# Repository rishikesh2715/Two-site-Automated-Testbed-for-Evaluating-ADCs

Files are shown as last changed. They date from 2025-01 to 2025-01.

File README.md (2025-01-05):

# Two-site-Automated-Testbed-for-Evaluating-ADCs

## Overview
The Two-site Automated Test System (ATS-2) is a custom-designed testbed for evaluating ADCs, specifically focused on testing the ADS7816. This comprehensive testing solution consists of a custom-designed device interface board, National Instruments VirtualBench integration, and automated test programs implemented in Python.

### Key Features:
- **Dual Testing Sites**: Capability to test two ADC devices simultaneously
- **Comprehensive Test Suite**: Includes all relevant parametric and functional tests
- **Automated Control**: Python-based test automation for consistent results
- **Relay-Based Interface**: Flexible configuration using G5NB-1A4 DC24 and J104D2C24VDC.15S relays
- **Power Management**: External 24V power supply for relay control

## Test Capabilities
The ATS-2 supports a comprehensive suite of tests including:
- Continuity Testing
- Power Supply Current Testing (Normal and Power-down modes)
- Leakage Current Testing
- Input Impedance Testing
- Linear Histogram Method for Code Edge Measurements
- Sinusoidal Histogram Method for Code Edge Measurements
- Offset and Offset Error Analysis
- Gain and Gain Error Analysis
- Missing Code Detection
- Integral Nonlinearity (INL) Analysis
- Differential Nonlinearity (DNL) Analysis
- Maximum Sampling Frequency Verification

## Hardware Specifications
### Device Under Test (DUT)
- **Target Device**: ADS7816
- **Features**: 
  - 200kHz sampling rate
  - Low power operation
  - Differential input
  - Serial interface
  - External reference and clock requirements
  - 5V power source operation

### Relay System
- **SPST-NO Relay**: G5NB-1A4 DC24
  - Power consumption: ~200mW
  - Operating current: ~8.3mA at 24V
  - Cost: $1.32

- **DPDT Relay**: J104D2C24VDC.15S
  - Power consumption: 150mW
  - Operating current: ~6.25mA at 24V
  - Cost: $1.21

## Software
The testbed includes a comprehensive suite of Python scripts for automated testing:
- `Combined_Hist_Tests.py`: Manages both linear and sinusoidal histogram testing
- `Continuity.py`: Performs continuity testing across all pins
- `InputImpedanceTest.py`: Measures input impedance characteristics
- `LeakageCurrents.py`: Tests for current leakage under various conditions
- `PwrSupplyCurrents.py`: Evaluates power supply current in different operating modes
- `Testing_Comb.py`: Main test orchestration script

## Getting Started
1. **Hardware Setup**:
   - Connect the VirtualBench device (VB8012-30DF182)
   - Apply 24V external power for relay control
   - Connect the DUT to the test board

2. **Software Requirements**:
   - Python 3.x
   - PyVirtualBench library
   - Required Python packages: numpy, matplotlib, tqdm, pandas

3. **Running Tests**:
   ```bash
   python Testing_Comb.py

## PCBWay - PCB Manufacturing and Assembly
![PCBWay](./Images/pcbway.png)
This project was proudly sponsored by **PCBWay**, a leading PCB manufacturer and assembler. They provided high-quality PCB manufacturing and assembly services, ensuring that the ATS-2 board was produced to the highest standards. Here's why PCBWay is a great choice for PCB production:

- **Exceptional Quality**: The PCBs produced by PCBWay have excellent build quality, with precise soldering and thorough assembly.
- **Fast Service**: PCBWay offers quick turnaround times, so your project can stay on track.
- **Comprehensive Services**: From prototyping to mass production, PCBWay provides services for all stages of PCB development, including multi-layer PCBs, advanced PCBs, flexible PCBs, and assembly services.
- **Affordable Pricing**: PCBWay offers competitive pricing without compromising quality.

To order this board through PCBWay:
1. Upload the provided Gerber files to PCBWay's portal
2. Select your preferences:
   - Min Track/spacing: 6/6 mil
   - Min hole size: 0.2mm
   - Recommended finish: Immersion Gold (ENIG)

If you're looking for a reliable partner to bring your PCB projects to life, check out [PCBWay](https://pcbway.com). With their extensive capabilities and top-notch customer support, PCBWay is the ideal choice for makers, engineers, and businesses alike.

## PCB Features
- Custom designed device interface board
- Relay-based switching matrix for flexible test configuration
- Support for dual device testing
- Professional 4-layer PCB design
- Integrated power management for both DUT and relay control
- Comprehensive test point access
- Industrial-grade components for reliability

## License
This project is open-source and available under the MIT License.

## Contributing
Contributions are welcome! Please feel free to submit pull requests or open issues for improvements and bug fixes.

## Acknowledgments
- Mr. Johnston and Dr. Dallas at Texas Tech University for project supervision
- National Instruments for VirtualBench support
- PCBWay for manufacturing partnership

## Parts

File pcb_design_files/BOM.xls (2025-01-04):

PCBWay Bom Quotation, Product No.:T-I6W845719A
Item # | *Designator | *Qty | Manufacturer | *Mfg Part # | Description / Value | Vendor Part # | *Package/Footprint | Mounting Type | Your Instructions / Notes | Assembly requirement | *Unit Price(1 set) | *Total | *Delivery Time | *Actual Purchase Mfg Part # | *PCBWay Note | Customer Reply | PCBWay Update
1 | C1, C4 | 2 |  |  | 5u『 』Unpolarized capacitor |  | C_Axial_L3.8mm_D2.6mm_P7.50mm_Horizontal | tht |  |  |  |  |  |  | [DNP
2 | C2, C3 | 2 |  |  | .1u『 』Unpolarized capacitor |  | C_Axial_L3.8mm_D2.6mm_P7.50mm_Horizontal | tht |  |  |  |  |  |  | [DNP
3 | IC1, IC2, IC3, IC4, IC5, IC6, IC7 | 7 | Nexperia | 74LVC595AD,118 | 74LVC595AD,118『 』74LVC595AD_118『 』IC 8BIT SHIFT REGISTER 16-SOIC『 』IC 8BIT SHIFT REGISTER 16-SOIC『 』Digikey『 』Shift Shift Register 1 Element 8 Bit 16-SO『 』74LVC595AD,118 | 1727-6688-1-ND | 74LVC595AD118『 』SO-16 Nexperia USA Inc.『 』16SOP | smt | https://www.snapeda.com/parts/74LVC595AD,118/Nexperia/view-part/?ref=eda『 』https://www.snapeda.com/parts/74LVC595AD,118/Nexperia/view-part/?ref=snap |  | $0.644 | $4.508 | 7-10 Workdays
4 | J1 | 1 | 3M Electronic Solutions Division『 』3M | 208-7391-55-1902 | DNP『 』Socket,Test&Burn-InSOIC,8Leads,0.15Width,1A,1000Vrms | 3M 208-7391-55-1902『 』38.51mm『 』Manufacturer Recommendations『 』February 19, 2001 |  | 3M_208-7391-55-1902『 』None | tht | https://www.snapeda.com/parts/208-7391-55-1902/Hartmann+Electronic/view-part/?ref=eda『 』https://www.snapeda.com/parts/208-7391-55-1902/Hartmann+Electronic/view-part/?ref=snap『 』https://www.snapeda.com/api/url_track_click_mouser/?unipart_id=12122657&manufacturer=3M Electronic Solutions Division&part_name=208-7391-55-1902&search_term=208-7391-55-1902 | DNP |  |  |  |  | [DNP
5 | J2, J8 | 2 |  |  | 25V_PS『 』Generic screw terminal, single row, 01x02, script generated (kicad-library-utils/schlib/autogen/connector/) |  | TerminalBlock_bornier-2_P5.08mm | tht |  |  | $0.505 | $1.010 |  | DB127V-5.08-2P-GN-S
6 | J3 | 1 |  |  | Multimeter『 』Generic screw terminal, single row, 01x03, script generated (kicad-library-utils/schlib/autogen/connector/) |  | TerminalBlock_bornier-3_P5.08mm | tht |  |  | $1.464 | $1.464 |  | DB127V-5.08-3P-GN-S
7 | J4 | 1 |  |  | 6V_PS『 』Generic screw terminal, single row, 01x02, script generated (kicad-library-utils/schlib/autogen/connector/) |  | TerminalBlock_bornier-2_P5.08mm | tht |  |  | $1.010 | $1.010 |  | DB127V-5.08-2P-GN-S
8 | J5 | 1 |  |  | Digital I/O『 』Generic screw terminal, single row, 01x14, script generated (kicad-library-utils/schlib/autogen/connector/) |  | PinHeader_1x14_P2.54mm_Vertical | tht |  |  | $1.226 | $1.226 |  | X6511WV-14H-C60D30
9 | J6 | 1 |  |  | FunctionGenerator『 』Generic screw terminal, single row, 01x02, script generated (kicad-library-utils/schlib/autogen/connector/) |  | TerminalBlock_bornier-2_P5.08mm | tht |  |  | $1.010 | $1.010 |  | DB127V-5.08-2P-GN-S
10 | J7 | 1 |  |  | 24V『 』Generic screw terminal, single row, 01x02, script generated (kicad-library-utils/schlib/autogen/connector/) |  | TerminalBlock_bornier-2_P5.08mm | tht |  |  | $1.010 | $1.010 |  | DB127V-5.08-2P-GN-S
11 | J9 | 1 | 3M Electronic Solutions Division『 』3M | 208-7391-55-1902 | DNP『 』Socket,Test&Burn-InSOIC,8Leads,0.15Width,1A,1000Vrms | 3M 208-7391-55-1902『 』38.51mm『 』Manufacturer Recommendations『 』February 19, 2001 |  | 3M_208-7391-55-1902『 』None | tht | https://www.snapeda.com/parts/208-7391-55-1902/Hartmann+Electronic/view-part/?ref=eda『 』https://www.snapeda.com/parts/208-7391-55-1902/Hartmann+Electronic/view-part/?ref=snap『 』https://www.snapeda.com/api/url_track_click_mouser/?unipart_id=12122657&manufacturer=3M Electronic Solutions Division&part_name=208-7391-55-1902&search_term=208-7391-55-1902 | DNP |  |  |  |  | [DNP
12 | K1, K10, K11, K12, K13, K17, K18, K20, K21, K23, K24, K25, K26, K27, K28, K29, K3, K32, K33, K34, K36, K37, K38, K39, K4, K40, K41, K42, K43, K44, K45, K46, K47, K48, K49, K5, K50, K51, K52, K53, K54, K55, K56, K59, K6, K7, K8, K9 | 48 | Omron Electronics | OJ-SS-112LMH2 | OJ-SS-112LMH2『 』Body Features: Insulation Special Features Tracking Index of Relay Base PTI250 | Product Weight 9 G | Product Weight .318 OZ | Contact Features: Contact Current Rating (Max) 8 AMP | Contact Arrangement 1 Form A (NO) | Contact Current Class 16 AMP | Contact Number of Poles 1 | Contact Material AgSnOInO | Dimensions: Product Width .401 INCH | Product Length 18.2 MM | Insulation Clearance Between Contact & Coil .125 INCH | Product Length .716 INCH | Product Height 14.7 MM | Length Class (Mechanical) 16 20『 』15.4 | 655-OJ-SS-112LMH2 | G5NB1A4DC5 | tht | https://www.mouser.co.uk/ProductDetail/TE-Connectivity-OEG/OJ-SS-112LMH2?qs=rXmh1mW8ce0s4UUbiGzobQ%3D%3D |  | $1.983 | $95.184 | 7-10 Workdays | G5NB-1A4 DC24
13 | K14, K15, K16, K22, K30, K31 | 6 | CIT Relay and Switch | G6K-2P-Y DC9 | G6K-2P-Y_DC9『 』Low Signal Relays - PCB ThruHole NoLatch 3.2 DPDT 9VDC 100mW | 653-G6K-2P-YDC9 | J104D2C24VDC.15S | tht | https://www.mouser.co.uk/ProductDetail/Omron-Electronics/G6K-2P-Y-DC9?qs=wkx8pu8tL7LXpnqEum69xQ%3D%3D |  | $2.282 | $13.692 | 7-10 Workdays | J104D2C24VDC.15S
14 | Q1, Q10, Q11, Q12, Q13, Q14, Q15, Q16, Q18, Q19, Q2, Q20, Q21, Q22, Q23, Q24, Q25, Q26, Q27, Q28, Q3, Q30, Q33, Q34, Q35, Q37, Q38, Q39, Q4, Q40, Q41, Q42, Q43, Q44, Q45, Q46, Q47, Q48, Q5, Q50, Q51, Q52, Q53, Q54, Q55, Q56, Q57, Q58, Q6, Q61, Q7, Q8, Q9, Qa21 | 54 | Vishay | IRL540PBF | IRL540PBF『 』MOSFET N-CH 100V HEXFET MOSFET『 』4.65 | 844-IRL540PBF | TO254P465X1024X2050-3P | tht | https://www.mouser.co.uk/ProductDetail/Vishay-Semiconductors/IRL540PBF?qs=cvaI6ThkwxvX4jX2UNqT3g%3D%3D |  | $1.769 | $95.526 | 7-10 Workdays
15 | R1, R10, R101, R103, R105, R107, R112, R115, R12, R14, R17, R19, R20, R21, R22, R23, R24, R26, R27, R29, R31, R32, R35, R37, R38, R4, R40, R42, R43, R45, R47, R49, R5, R51, R52, R54, R55, R56, R57, R58, R61, R63, R66, R69, R7, R71, R73, R75, R80, R83, R86, R9, R97, R99 | 54 |  |  | 2k『 』Resistor, US symbol |  | R_0805_2012Metric_Pad1.20x1.40mm_HandSolder | smt |  |  | $0.002 | $0.108 |  | RC0805FR-072KL
16 | R100, R102, R104, R106, R108, R11, R111, R113, R114, R116, R117, R118, R119, R124, R13, R15, R16, R18, R2, R25, R28, R3, R34, R36, R39, R41, R44, R46, R48, R50, R53, R59, R6, R60, R64, R65, R67, R68, R70, R72, R74, R76, R79, R8, R81, R82, R84, R85, R87, R92, R93, R94, R98, Ra79 | 54 |  |  | 10k『 』Resistor, US symbol |  | R_0805_2012Metric_Pad1.20x1.40mm_HandSolder | smt |  |  | $0.004 | $0.216 |  | RC0805FR-0710KL
17 | R30, R33 | 2 |  |  | 1R『 』Resistor, US symbol |  | R_0805_2012Metric_Pad1.20x1.40mm_HandSolder | smt |  |  | $0.107 | $0.214 |  | RC0805FR-071RL
 |  |  |  |  |  |  |  |  |  |  | Component Cost | $216.18
 |  |  |  |  |  |  |  |  |  |  | Assembly Cost | $88.00
 |  |  |  |  |  |  |  |  |  |  | PCB Cost | $133.63
 |  |  |  |  |  |  |  |  |  |  | V1 Member 1% off | -$2.22
 |  |  |  |  |  |  |  |  |  |  | All Total 1 Sets | $435.59
客户BOM中部分没有型号，推荐了*Actual Purchase Mfg Part # *PCBWay Note请确认

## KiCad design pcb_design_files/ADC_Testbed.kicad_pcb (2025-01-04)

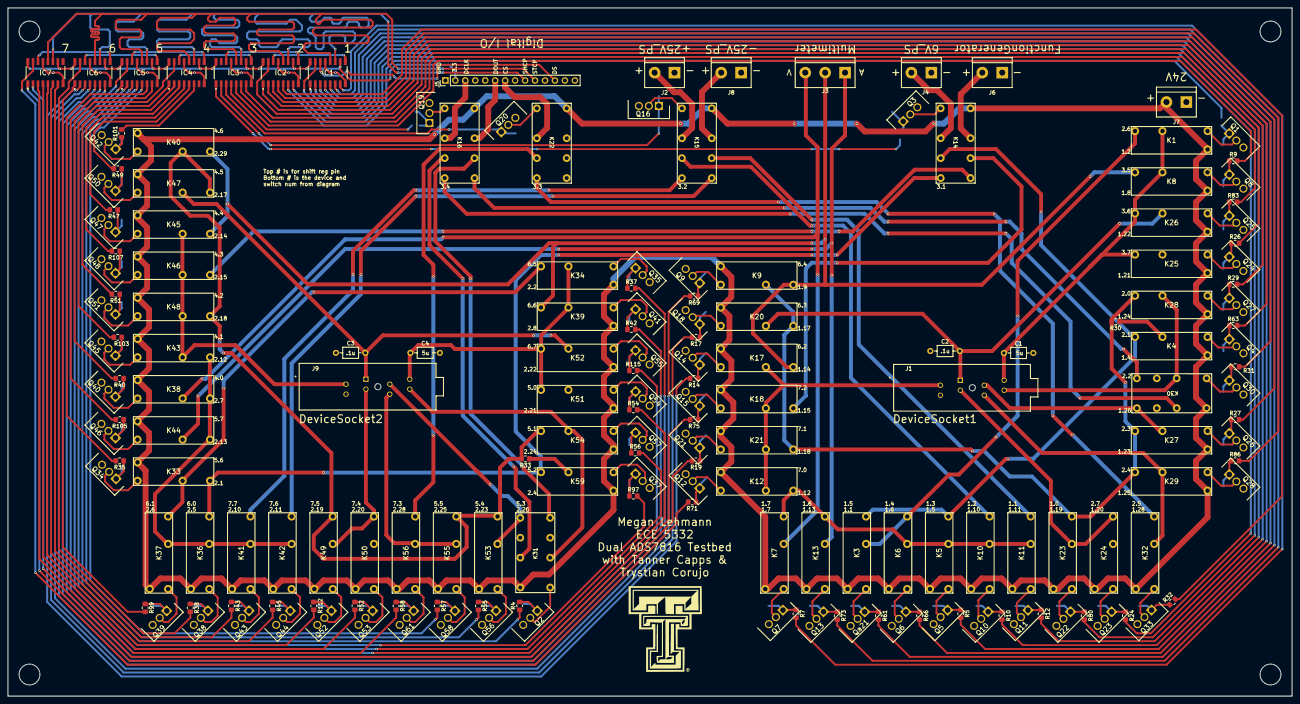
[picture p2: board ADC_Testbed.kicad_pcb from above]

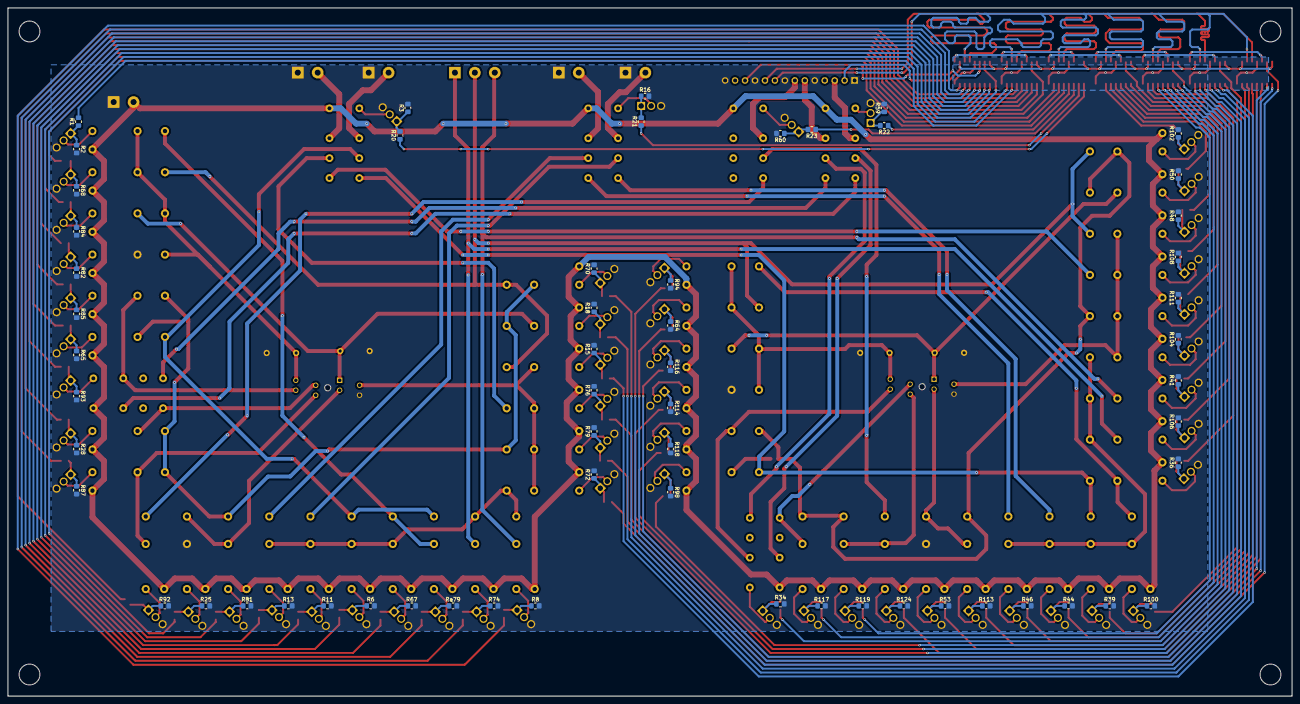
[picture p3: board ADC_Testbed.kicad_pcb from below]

Board: 2 copper layers, 327.5 x 175.5 mm, 238 parts (59 on the bottom side), 220 nets.

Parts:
C1, C4: 5u; C_Axial_L3.8mm_D2.6mm_P7.50mm_Horizontal
C2, C3: .1u; C_Axial_L3.8mm_D2.6mm_P7.50mm_Horizontal
IC1, IC2, IC3, IC4, IC5, IC6, IC7: 74LVC595AD_118; 74LVC595AD118
J1, J9: DNP; 3M_208-7391-55-1902
J2: +25V_PS; TerminalBlock_bornier-2_P5.08mm
J3: Multimeter; TerminalBlock_bornier-3_P5.08mm
J4: 6V_PS; TerminalBlock_bornier-2_P5.08mm
J5: Digital I/O; PinHeader_1x14_P2.54mm_Vertical
J6: FunctionGenerator; TerminalBlock_bornier-2_P5.08mm
J7: 24V; TerminalBlock_bornier-2_P5.08mm
J8: -25V_PS; TerminalBlock_bornier-2_P5.08mm
K1, K3, K4, K5, K6, K7, K8, K9, K10, K11, K12, K13, K17, K18, K20, K21, K23, K24, K25, K26, K27, K28, K29, K32, K33, K34, K36, K37, K38, K39, K40, K41, K42, K43, K44, K45, K46, K47, K48, K49, K50, K51, K52, K53, K54, K55, K56, K59: OJ-SS-112LMH2; G5NB1A4DC5
K14, K15, K16, K22, K30, K31: G6K-2P-Y_DC9; J104D2C24VDC.15S
Q1, Q2, Q3, Q4, Q5, Q6, Q7, Q8, Q9, Q10, Q11, Q12, Q13, Q14, Q15, Q16, Q18, Q19, Q20, Q21, Q22, Q23, Q24, Q25, Q26, Q27, Q28, Q30, Q33, Q34, Q35, Q37, Q38, Q39, Q40, Q41, Q42, Q43, Q44, Q45, Q46, Q47, Q48, Q50, Q51, Q52, Q53, Q54, Q55, Q56, Q57, Q58, Q61: IRL540PBF; TO254P465X1024X2050-3P
Qa21: IRL540PBF; TO254P465X1024X2050-3P
R1, R4, R5, R7, R9, R10, R12, R14, R17, R19, R20, R21, R22, R23, R24, R26, R27, R29, R31, R32, R35, R37, R38, R40, R42, R43, R45, R47, R49, R51, R52, R54, R55, R56, R57, R58, R61, R63, R66, R69, R71, R73, R75, R80, R83, R86, R97, R99, R101, R103, R105, R107, R112, R115: 2k; R_0805_2012Metric_Pad1.20x1.40mm_HandSolder
R2, R3, R6, R8, R11, R13, R15, R16, R18, R25, R28, R34, R36, R39, R41, R44, R46, R48, R50, R53, R59, R60, R64, R65, R67, R68, R70, R72, R74, R76, R79, R81, R82, R84, R85, R87, R92, R93, R94, R98, R100, R102, R104, R106, R108, R111, R113, R114, R116, R117, R118, R119, R124: 10k; R_0805_2012Metric_Pad1.20x1.40mm_HandSolder
R30, R33: 1R; R_0805_2012Metric_Pad1.20x1.40mm_HandSolder
Ra79: 10k; R_0805_2012Metric_Pad1.20x1.40mm_HandSolder

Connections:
0: J5.3, K16.6 (COM_2)
2: J5.6, K16.3 (COM_1)
3: J5.7, K22.6 (COM_2)
4: IC1.11 (SHCP), IC2.11 (SHCP), IC3.11 (SHCP), IC4.11 (SHCP), IC5.11 (SHCP), IC6.11 (SHCP), IC7.11 (SHCP), J5.9
5: IC1.12 (STCP), IC2.12 (STCP), IC3.12 (STCP), IC4.12 (STCP), IC5.12 (STCP), IC6.12 (STCP), IC7.12 (STCP), J5.10
6: IC1.14 (DS), J5.12
+3.3V: IC1.10 (~MR), IC1.16 (VCC), IC2.10 (~MR), IC2.16 (VCC), IC3.10 (~MR), IC3.16 (VCC), IC4.10 (~MR), IC4.16 (VCC), IC5.10 (~MR), IC5.16 (VCC), IC6.10 (~MR), IC6.16 (VCC), IC7.10 (~MR), IC7.16 (VCC), J5.2
+24V: J7.2, K1.2 (COIL_2), K3.2 (COIL_2), K4.2 (COIL_2), K5.2 (COIL_2), K6.2 (COIL_2), K7.2 (COIL_2), K8.2 (COIL_2), K9.2 (COIL_2), K10.2 (COIL_2), K11.2 (COIL_2), K12.2 (COIL_2), K13.2 (COIL_2), K14.1 (COIL_+), K15.1 (COIL_+), K16.1 (COIL_+), K17.2 (COIL_2), K18.2 (COIL_2), K20.2 (COIL_2), K21.2 (COIL_2), K22.1 (COIL_+), K23.2 (COIL_2), K24.2 (COIL_2), K25.2 (COIL_2), K26.2 (COIL_2), K27.2 (COIL_2), K28.2 (COIL_2), K29.2 (COIL_2), K30.1 (COIL_+), K31.1 (COIL_+), K32.2 (COIL_2), K33.2 (COIL_2), K34.2 (COIL_2), K36.2 (COIL_2), K37.2 (COIL_2), K38.2 (COIL_2), K39.2 (COIL_2), K40.2 (COIL_2), K41.2 (COIL_2), K42.2 (COIL_2), K43.2 (COIL_2), K44.2 (COIL_2), K45.2 (COIL_2), K46.2 (COIL_2), K47.2 (COIL_2), K48.2 (COIL_2), K49.2 (COIL_2), K50.2 (COIL_2), K51.2 (COIL_2), K52.2 (COIL_2), K53.2 (COIL_2), K54.2 (COIL_2), K55.2 (COIL_2), K56.2 (COIL_2), K59.2 (COIL_2)
+HighVoltage: J2.2, K15.6 (COM_2)
-HighVoltage: J8.2, K15.3 (COM_1)
/Relay_Control1/OUT: K1.3 (COM), K3.4 (NO), K6.3 (COM)
/Relay_Control2/OUT: C1.1, J1.8, K1.4 (NO), K8.4 (NO), K25.3 (COM), K26.3 (COM)
/Relay_Control4/OUT: K4.4 (NO), R30.1
/Relay_Control10/OUT: K5.4 (NO), K6.4 (NO), K7.3 (COM), K10.4 (NO), K11.4 (NO), K12.3 (COM), K13.3 (COM)
/Relay_Control12/OUT: J1.2, K12.4 (NO), K17.4 (NO), K18.4 (NO), K21.4 (NO)
/Relay_Control17/IN: K9.4 (NO), K20.3 (COM), K21.3 (COM), K23.3 (COM), K27.3 (COM), K28.3 (COM), K29.3 (COM), R30.2
/Relay_Control17/OUT: C2.2, J1.1, K20.4 (NO), K26.4 (NO)
/Relay_Control19/OUT: J1.3, K23.4 (NO), K24.3 (COM)
/Relay_Control23/OUT: J1.7, K27.4 (NO), K30.4 (N.O._1)
/Relay_Control24/OUT: J1.6, K28.4 (NO), K30.6 (COM_2)
/Relay_Control25/OUT: J1.5, K29.4 (NO), K32.4 (NO)
/Relay_Control29/OUT: K33.4 (NO), K34.3 (COM), K37.3 (COM)
/Relay_Control30/OUT: C4.1, J9.8, K34.4 (NO), K39.4 (NO), K51.3 (COM), K52.3 (COM)
/Relay_Control32/OUT: K59.4 (NO), R33.1
/Relay_Control33/OUT: K36.4 (NO), K37.4 (NO), K38.3 (COM), K41.4 (NO), K42.4 (NO), K43.3 (COM), K44.3 (COM)
/Relay_Control37/OUT: K40.4 (NO), K47.3 (COM), K48.3 (COM), K49.3 (COM), K53.3 (COM), K54.3 (COM), K55.3 (COM), R33.2
/Relay_Control40/OUT: J9.2, K43.4 (NO), K45.4 (NO), K46.4 (NO), K48.4 (NO)
/Relay_Control45/OUT: C3.2, J9.1, K47.4 (NO), K52.4 (NO)
/Relay_Control47/OUT: J9.3, K49.4 (NO), K50.3 (COM)
/Relay_Control51/OUT: J9.7, K31.4 (N.O._1), K53.4 (NO)
/Relay_Control52/OUT: J9.6, K31.6 (COM_2), K54.4 (NO)
/Relay_Control53/OUT: J9.5, K55.4 (NO), K56.4 (NO)
Ammeter: J3.1, K13.4 (NO), K44.4 (NO)
CS_1: IC3.1 (Q1), R20.1
CS_2: IC3.2 (Q2), R21.1
CS_3: IC3.4 (Q4), R22.1
CS_4: IC3.3 (Q3), R23.1
D1CS1: IC1.5 (Q5), R61.2
D1CS2: IC2.6 (Q6), R1.2
D1CS4: IC2.1 (Q1), R63.2
D1CS5: IC1.3 (Q3), R5.2
D1CS6: IC1.4 (Q4), R66.2
D1CS7: IC1.7 (Q7), R7.2
D1CS8: IC3.5 (Q5), R9.2
D1CS9: IC6.4 (Q4), R69.2
D1CS10: IC1.2 (Q2), R10.2
D1CS11: IC1.1 (Q1), R12.2
D1CS12: IC7.15 (Q0), R71.2
D1CS13: IC1.6 (Q6), R73.2
D1CS14: IC6.2 (Q2), R14.2
D1CS15: IC7.2 (Q2), R75.2
D1CS17: IC6.3 (Q3), R17.2
D1CS18: IC7.1 (Q1), R19.2
D1CS19: IC1.15 (Q0), R80.2
D1CS20: IC2.7 (Q7), R24.2
D1CS21: IC3.7 (Q7), R26.2
D1CS22: IC3.6 (Q6), R83.2
D1CS23: IC2.3 (Q3), R27.2
D1CS24: IC2.15 (Q0), R29.2
D1CS25: IC2.4 (Q4), R86.2
D1CS26: IC2.2 (Q2), R31.1
D1CS28: IC2.5 (Q5), R32.2
D1_+High: K10.3 (COM), K15.7 (N.C._2)
D1_-High: K11.3 (COM), K15.2 (N.C._1)
D1_CS: K22.5 (N.O._2), K32.3 (COM)
D1_DCLK: K16.5 (N.O._2), K30.3 (COM_1)
D1_DOUT: K16.4 (N.O._1), K30.5 (N.O._2)
D1_Low: K3.3 (COM), K4.3 (COM), K5.3 (COM), K14.7 (N.C._2)
D1_func: K14.2 (N.C._1), K18.3 (COM)
D2CS1: IC5.6 (Q6), R35.2
D2CS2: IC6.5 (Q5), R37.2
D2CS4: IC5.2 (Q2), R97.2
D2CS5: IC6.15 (Q0), R38.2
D2CS6: IC6.1 (Q1), R99.2
D2CS7: IC4.15 (Q0), R40.2
D2CS8: IC6.6 (Q6), R42.2
D2CS9: IC4.6 (Q6), R101.2
D2CS10: IC7.7 (Q7), R43.2
D2CS11: IC7.6 (Q6), R45.2
D2CS12: IC4.1 (Q1), R103.2
D2CS13: IC5.7 (Q7), R105.2
D2CS14: IC4.4 (Q4), R47.2
D2CS15: IC4.3 (Q3), R107.2
D2CS17: IC4.5 (Q5), R49.2
D2CS18: IC4.2 (Q2), R51.2
D2CS19: IC7.5 (Q5), R112.2
D2CS20: IC7.4 (Q4), R52.2
D2CS21: IC5.15 (Q0), R54.2
D2CS22: IC6.7 (Q7), R115.2
D2CS23: IC5.4 (Q4), R55.2
D2CS24: IC5.1 (Q1), R56.2
D2CS25: IC5.5 (Q5), R57.2
D2CS26: IC5.3 (Q3), R4.1
D2CS28: IC7.3 (Q3), R58.2
D2_+High: K15.5 (N.O._2), K41.3 (COM)
D2_-High: K15.4 (N.O._1), K42.3 (COM)
D2_CS: K22.7 (N.C._2), K56.3 (COM)
D2_DCLK: K16.7 (N.C._2), K31.3 (COM_1)
D2_DOUT: K16.2 (N.C._1), K31.5 (N.O._2)
D2_Low: K14.5 (N.O._2), K33.3 (COM), K36.3 (COM), K59.3 (COM)
D2_func: K14.4 (N.O._1), K46.3 (COM)
GND: C1.2, C2.1, C3.1, C4.2, IC1.8 (GND), IC1.13 (~OE), IC2.8 (GND), IC2.13 (~OE), IC3.8 (GND), IC3.13 (~OE), IC4.8 (GND), IC4.13 (~OE), IC5.8 (GND), IC5.13 (~OE), IC6.8 (GND), IC6.13 (~OE), IC7.8 (GND), IC7.13 (~OE), J1.4, J2.1, J4.1, J5.1, J5.5, J5.8, J5.11, J5.14, J6.1, J7.1, J8.1, J9.4, K24.4 (NO), K25.4 (NO), K50.4 (NO), K51.4 (NO), Q1.3 (S), Q2.3 (S), Q3.3 (S), Q4.3 (S), Q5.3 (S), Q6.3 (S), Q7.3 (S), Q8.3 (S), Q9.3 (S), Q10.3 (S), Q11.3 (S), Q12.3 (S), Q13.3 (S), Q14.3 (S), Q15.3 (S), Q16.3 (S), Q18.3 (S), Q19.3 (S), Q20.3 (S), Q21.3 (S), Q22.3 (S), Q23.3 (S), Q24.3 (S), Q25.3 (S), Q26.3 (S), Q27.3 (S), Q28.3 (S), Q30.3 (S), Q33.3 (S), Q34.3 (S), Q35.3 (S), Q37.3 (S), Q38.3 (S), Q39.3 (S), Q40.3 (S), Q41.3 (S), Q42.3 (S), Q43.3 (S), Q44.3 (S), Q45.3 (S), Q46.3 (S), Q47.3 (S), Q48.3 (S), Q50.3 (S), Q51.3 (S), Q52.3 (S), Q53.3 (S), Q54.3 (S), Q55.3 (S), Q56.3 (S), Q57.3 (S), Q58.3 (S), Q61.3 (S), Qa21.3 (S), R2.2, R3.2, R6.2, R8.2, R11.2, R13.2, R15.2, R16.2, R18.2, R25.2, R28.2, R34.2, R36.2, R39.2, R41.2, R44.2, R46.2, R48.2, R50.2, R53.2, R59.2, R60.2, R64.2, R65.2, R67.2, R68.2, R70.2, R72.2, R74.2, R76.2, R79.2, R81.2, R82.2, R84.2, R85.2, R87.2, R92.2, R93.2, R94.2, R98.2, R100.2, R102.2, R104.2, R106.2, R108.2, R111.2, R113.2, R114.2, R116.2, R117.2, R118.2, R119.2, R124.2, Ra79.2
LowVoltage: J4.2, K14.6 (COM_2)
MultiOut: J3.2, K8.3 (COM), K9.3 (COM), K17.3 (COM), K39.3 (COM), K40.3 (COM), K45.3 (COM)
unnamed: IC1.9 (Q7S), IC2.14 (DS)
unnamed: IC2.9 (Q7S), IC3.14 (DS)
unnamed: IC3.9 (Q7S), IC4.14 (DS)
unnamed: IC4.9 (Q7S), IC5.14 (DS)
unnamed: IC5.9 (Q7S), IC6.14 (DS)
unnamed: IC6.9 (Q7S), IC7.14 (DS)
unnamed: K1.1 (COIL_1), Q1.2 (D)
unnamed: K3.1 (COIL_1), Qa21.2 (D)
unnamed: K4.1 (COIL_1), Q4.2 (D)
unnamed: K5.1 (COIL_1), Q5.2 (D)
unnamed: K6.1 (COIL_1), Q6.2 (D)
unnamed: K7.1 (COIL_1), Q7.2 (D)
unnamed: K8.1 (COIL_1), Q8.2 (D)
unnamed: K9.1 (COIL_1), Q9.2 (D)
unnamed: K10.1 (COIL_1), Q10.2 (D)
unnamed: K11.1 (COIL_1), Q11.2 (D)
unnamed: K12.1 (COIL_1), Q12.2 (D)
unnamed: K13.1 (COIL_1), Q13.2 (D)
unnamed: K14.8 (COIL_-), Q3.2 (D)
unnamed: K15.8 (COIL_-), Q16.2 (D)
unnamed: K16.8 (COIL_-), Q19.2 (D)
unnamed: K17.1 (COIL_1), Q14.2 (D)
unnamed: K18.1 (COIL_1), Q15.2 (D)
unnamed: K20.1 (COIL_1), Q18.2 (D)
unnamed: K21.1 (COIL_1), Q21.2 (D)
unnamed: K22.8 (COIL_-), Q20.2 (D)
unnamed: K23.1 (COIL_1), Q22.2 (D)
unnamed: K24.1 (COIL_1), Q23.2 (D)
unnamed: K25.1 (COIL_1), Q24.2 (D)
unnamed: K26.1 (COIL_1), Q25.2 (D)
unnamed: K27.1 (COIL_1), Q26.2 (D)
unnamed: K28.1 (COIL_1), Q27.2 (D)
unnamed: K29.1 (COIL_1), Q28.2 (D)
unnamed: K30.8 (COIL_-), Q30.2 (D)
unnamed: K31.8 (COIL_-), Q2.2 (D)
unnamed: K32.1 (COIL_1), Q33.2 (D)
unnamed: K33.1 (COIL_1), Q34.2 (D)
unnamed: K34.1 (COIL_1), Q35.2 (D)
unnamed: K36.1 (COIL_1), Q38.2 (D)
unnamed: K37.1 (COIL_1), Q39.2 (D)
unnamed: K38.1 (COIL_1), Q40.2 (D)
unnamed: K39.1 (COIL_1), Q41.2 (D)
unnamed: K40.1 (COIL_1), Q42.2 (D)
unnamed: K41.1 (COIL_1), Q43.2 (D)
unnamed: K42.1 (COIL_1), Q44.2 (D)
unnamed: K43.1 (COIL_1), Q45.2 (D)
unnamed: K44.1 (COIL_1), Q46.2 (D)
unnamed: K45.1 (COIL_1), Q47.2 (D)
unnamed: K46.1 (COIL_1), Q48.2 (D)
unnamed: K47.1 (COIL_1), Q50.2 (D)
unnamed: K48.1 (COIL_1), Q51.2 (D)
unnamed: K49.1 (COIL_1), Q52.2 (D)
unnamed: K50.1 (COIL_1), Q53.2 (D)
unnamed: K51.1 (COIL_1), Q54.2 (D)
unnamed: K52.1 (COIL_1), Q55.2 (D)
unnamed: K53.1 (COIL_1), Q56.2 (D)
unnamed: K54.1 (COIL_1), Q57.2 (D)
unnamed: K55.1 (COIL_1), Q58.2 (D)
unnamed: K56.1 (COIL_1), Q61.2 (D)
unnamed: K59.1 (COIL_1), Q37.2 (D)
unnamed: Q1.1 (G), R1.1, R2.1
unnamed: Q2.1 (G), R4.2, R34.1
unnamed: Q3.1 (G), R3.1, R20.2
unnamed: Q4.1 (G), R63.1, R65.1
unnamed: Q5.1 (G), R5.1, R6.1
unnamed: Q6.1 (G), R66.1, R67.1
unnamed: Q7.1 (G), R7.1, R8.1
unnamed: Q8.1 (G), R9.1, R68.1
unnamed: Q9.1 (G), R69.1, R70.1
unnamed: Q10.1 (G), R10.1, R11.1
unnamed: Q11.1 (G), R12.1, R13.1
unnamed: Q12.1 (G), R71.1, R72.1
unnamed: Q13.1 (G), R73.1, R74.1
unnamed: Q14.1 (G), R14.1, R15.1
unnamed: Q15.1 (G), R75.1, R76.1
unnamed: Q16.1 (G), R16.1, R21.2
unnamed: Q18.1 (G), R17.1, R18.1
unnamed: Q19.1 (G), R22.2, R59.1
unnamed: Q20.1 (G), R23.2, R60.1
unnamed: Q21.1 (G), R19.1, R79.1
unnamed: Q22.1 (G), R80.1, R81.1
unnamed: Q23.1 (G), R24.1, R25.1
unnamed: Q24.1 (G), R26.1, R82.1
unnamed: Q25.1 (G), R83.1, R84.1
unnamed: Q26.1 (G), R27.1, R28.1
unnamed: Q27.1 (G), R29.1, R85.1
unnamed: Q28.1 (G), R86.1, R87.1
unnamed: Q30.1 (G), R31.2, R93.1
unnamed: Q33.1 (G), R32.1, R92.1
unnamed: Q34.1 (G), R35.1, R36.1
unnamed: Q35.1 (G), R37.1, R94.1
unnamed: Q37.1 (G), R97.1, R98.1
unnamed: Q38.1 (G), R38.1, R39.1
unnamed: Q39.1 (G), R99.1, R100.1
unnamed: Q40.1 (G), R40.1, R41.1
unnamed: Q41.1 (G), R42.1, R64.1
unnamed: Q42.1 (G), R101.1, R102.1
unnamed: Q43.1 (G), R43.1, R44.1
unnamed: Q44.1 (G), R45.1, R46.1
unnamed: Q45.1 (G), R103.1, R104.1
unnamed: Q46.1 (G), R105.1, R106.1
unnamed: Q47.1 (G), R47.1, R48.1
unnamed: Q48.1 (G), R107.1, R108.1
unnamed: Q50.1 (G), R49.1, R50.1
unnamed: Q51.1 (G), R51.1, R111.1
unnamed: Q52.1 (G), R112.1, R113.1
unnamed: Q53.1 (G), R52.1, R53.1
unnamed: Q54.1 (G), R54.1, R114.1
unnamed: Q55.1 (G), R115.1, R116.1
unnamed: Q56.1 (G), R55.1, R117.1
unnamed: Q57.1 (G), R56.1, R118.1
unnamed: Q58.1 (G), R57.1, R119.1
unnamed: Q61.1 (G), R58.1, R124.1
unnamed: Qa21.1 (G), R61.1, Ra79.1
Voltmeter: J3.3, K7.4 (NO), K38.4 (NO)
function: J6.2, K14.3 (COM_1)

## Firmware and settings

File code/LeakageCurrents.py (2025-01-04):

import numpy as np
import time
import matplotlib.pyplot as plt
from tqdm import tqdm
from pyvirtualbench import (
    PyVirtualBench, Polarity, ClockPhase, PyVirtualBenchException, Waveform, DmmFunction
)
import math


# Configuration Parameters
VB_DEVICE = "VB8012-30DF182"
BUS = f"{VB_DEVICE}/spi/0"
PWR_CHANNEL = "ps/+6V"
CLOCK_RATE = 200000 * 16
CHIP_SELECT_POLARITY = Polarity.IDLE_HIGH
CLOCK_PHASE = ClockPhase.FIRST_EDGE
CLOCK_POLARITY = Polarity.IDLE_LOW

WAVE_TYPE = Waveform.DC
AMPLITUDE = 5 #Amplitude shown in Pk-2-Pk Voltage. Actual peak voltage is 2.5 V
FREQ = 1.0  # Hz
DUTY_CYCLE = 50.0  # %
DC_OFFSET = 5.0

SAMPLE_COUNT = 500
VREF = 5.0  # Reference voltage in Volts
HITS_PER_VALUE = 1
VLSB = VREF/4094

PEAK = AMPLITUDE


def run_Leakage_low(dmm):
    total = 0
    for _ in range(50):
        total += dmm.read()
    leakage_curr = total / 50
    return leakage_curr

def run_Leakage_high(dmm):
    total = 0
    for _ in range(50):
        total += dmm.read()
    leakage_curr = total / 50
    return leakage_curr

if __name__ == "__main__":
    try:
        vb = PyVirtualBench(VB_DEVICE)
        fgen = vb.acquire_function_generator()
        fgen.configure_standard_waveform(WAVE_TYPE, AMPLITUDE, DC_OFFSET, FREQ, DUTY_CYCLE)
        dmm = vb.acquire_digital_multimeter()
        dmm.configure_measurement(DmmFunction.DC_CURRENT, True, 0.1)
        pwr_sup = vb.acquire_power_supply()
        pwr_sup.enable_all_outputs(True)
        pwr_sup.configure_voltage_output(PWR_CHANNEL, VREF, 0.5)
        input("prep for low leakage test...")
        leakage_curr_low = run_Leakage_low(dmm)

        input("prep for High leakage test...")
        fgen.run()
        leakage_curr_high = run_Leakage_high(dmm)

        fgen.stop()
        print(f"Results for low input voltage: {leakage_curr_low * 1000} mA")
        print(f"Results for high input voltage: {leakage_curr_high * 1000} mA")


    except:
        pass
    dmm.release()
    pwr_sup.enable_all_outputs(False)
    pwr_sup.release()
    fgen.release()
    vb.release()

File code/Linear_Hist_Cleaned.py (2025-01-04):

import numpy as np
import matplotlib.pyplot as plt
from tqdm import tqdm
from pyvirtualbench import (
    PyVirtualBench, Polarity, ClockPhase, PyVirtualBenchException, Waveform
)

# Configuration Parameters
VB_DEVICE = "VB8012-30DF182"
BUS = f"{VB_DEVICE}/spi/0"
PWR_CHANNEL = "ps/+6V"
CLOCK_RATE = 200000 * 16
CHIP_SELECT_POLARITY = Polarity.IDLE_HIGH
CLOCK_PHASE = ClockPhase.FIRST_EDGE
CLOCK_POLARITY = Polarity.IDLE_LOW

WAVE_TYPE = Waveform.DC
AMPLITUDE = 0.0
FREQ = 400.0  # Hz
DUTY_CYCLE = 50.0  # %
DC_OFFSET = 0.00

VREF = 5.0  # Reference voltage in Volts
HITS_PER_VALUE = 1
STEP_SIZE = 0.0002  # 0.1 mV step size
VLSB = VREF/4094


def generate_voltage_steps():
    """Generate expected voltage values for ascending and descending ramps."""
    num_steps = int(VREF / STEP_SIZE) + 1
    up = [i * STEP_SIZE * 1000 for i in range(num_steps)]
    down = [(num_steps - i - 1) * STEP_SIZE * 1000 for i in range(num_steps)]
    return up, down

def initialize_virtualbench():
    """Initialize VirtualBench and acquire resources."""
    vb = PyVirtualBench(VB_DEVICE)
    fgen = vb.acquire_function_generator()
    spi = vb.acquire_serial_peripheral_interface(BUS)
    return vb, fgen, spi

def configure_instruments(fgen, spi):
    """Configure power supply, function generator, and SPI interface."""
    spi.configure_bus(CLOCK_RATE, CLOCK_POLARITY, CLOCK_PHASE, CHIP_SELECT_POLARITY)
    fgen.configure_standard_waveform(WAVE_TYPE, AMPLITUDE, DC_OFFSET, FREQ, DUTY_CYCLE)
    fgen.run()

def perform_measurement(spi, fgen, voltage_mv, output_codes_list):
    """Perform a single ADC measurement."""
    dc_offset = voltage_mv / 1000.0  # Convert mV to V
    fgen.configure_standard_waveform(WAVE_TYPE, AMPLITUDE, dc_offset, FREQ, DUTY_CYCLE)

    total = 0
    for _ in range(HITS_PER_VALUE):
        read = spi.write_read([0xFF, 0x00], 2, 2)
        masked_upper = read[0] & 0x1F
        merged = (masked_upper << 8) | read[1]
        merged = merged >> 1
        total += merged

    averaged_code = np.round(total / HITS_PER_VALUE)
    #averaged_code = np.round(((1+0.000663 -0.000138)*(total/HITS_PER_VALUE))+(-7.991106-1.264181))
    output_codes_list.append(averaged_code)

def cleanup_instruments(vb, fgen, spi):
    """Release and reset all instruments."""
    try:
        fgen.stop()
        fgen.release()
        spi.release()
        vb.release()
    except Exception as e:
        print(f"Error during cleanup: {e}")

def calculate_best_fit_inl_dnl(inl):
    """Calculate best-fit INL and DNL using linear regression."""
    codes = np.arange(len(inl))
    best_fit = np.polyfit(codes, inl, 1)  # Linear regression
    gain, offset = best_fit
    best_fit_func = gain * codes + offset

    best_fit_inl = inl - best_fit_func
    best_fit_dnl = np.diff(best_fit_inl, prepend=0)

    return best_fit_inl, best_fit_dnl, gain, offset

def calculate_metrics(output_codes_up, output_codes_down, up):
    """Calculate metrics: Combined Codes, Code Widths, INL/DNL."""
    output_codes_down.reverse()
    combined_codes = [(up + down) // 2 for up, down in zip(output_codes_up, output_codes_down)]
    print(len(combined_codes))
    print(len(range(0,int(VREF/STEP_SIZE))))
    ideal_gain, ideal_offset = np.polyfit(range(0,int(VREF/STEP_SIZE) + 1), up, 1)
    #actual_gain, actual_offset = np.polyfit(range(0,int(VREF/STEP_SIZE) + 1), combined_codes, 1)
    #print(f"Ideal Gain of the Transfer Curve: {ideal_gain}")
    #print(f"Ideal Offset of the Transfer Curve: {ideal_offset}")
    hits = [0] * 4096
    for code in combined_codes:
        hits[int(code)] += 1

    avg_hits = sum(hits) / (4096 - 2)
    cw_combined = [hit / avg_hits for hit in hits[1:-1]]
    avg_code_width = np.mean(cw_combined)


    dnl = [cw - 1 for cw in cw_combined]
    inl = np.cumsum(dnl)

    best_fit_inl, best_fit_dnl, gain, offset = calculate_best_fit_inl_dnl(inl)
    avg_best_fit_inl = np.mean(np.abs(best_fit_inl))
    avg_best_fit_dnl = np.mean(np.abs(best_fit_dnl))

    avg_volts_per_code = VREF / 4096 * avg_code_width

    return (combined_codes, cw_combined, dnl, inl, best_fit_inl, best_fit_dnl, 
            gain, offset, avg_code_width, avg_volts_per_code, avg_best_fit_inl, avg_best_fit_dnl, ideal_gain, ideal_offset)

def print_metrics(gain, offset, avg_code_width, avg_volts_per_code, avg_best_fit_inl, avg_best_fit_dnl, ideal_gain, ideal_offset):
    """Print calculated metrics."""
    #print(f"Actual Gain of the Transfer Curve: {actual_gain}")
    #print(f"Actual Offset of the Transfer Curve: {actual_offset}")
    #gain_error = 100*((gain/ideal_gain) - 1)
    #offset_error = 100*((offset/ideal_offset) - 1)
    
    print(f"Gain (Best-Fit Slope): {gain:.6f} LSBs")
    print(f"Offset (Best-Fit Intercept): {offset:.6f} LSBs")
    #print(f"Gain Error: {gain_error} %")
    #print(f"Offset Error: {offset_error} %")
    print(f"Average Code Width: {avg_code_width:.6f} LSBs")
    print(f"Average Volts per Code: {avg_volts_per_code:.6f} V")
    print(f"Average Best-Fit INL: {avg_best_fit_inl:.6f} LSBs")
    print(f"Average Best-Fit DNL: {avg_best_fit_dnl:.6f} LSBs")

def plot_inl_dnl(inl, dnl, best_fit_inl, best_fit_dnl):
    """Plot INL and DNL curves with best-fit lines."""
    plt.figure(figsize=(14, 6))
    plt.plot(inl, label='Endpoint INL (LSBs)', color='blue')
    plt.plot(best_fit_inl, label='Best-Fit INL (LSBs)', linestyle='--', color='green')
    plt.title('INL Curve')
    plt.xlabel('Output Code')
    plt.ylabel('INL (LSBs)')
    plt.legend()
    plt.grid(True)
    plt.show()

    plt.figure(figsize=(14, 6))
    plt.plot(dnl, label='Endpoint DNL (LSBs)', color='red')
    plt.plot(best_fit_dnl, label='Best-Fit DNL (LSBs)', linestyle='--', color='orange')
    plt.title('DNL Curve')
    plt.xlabel('Output Code')
    plt.ylabel('DNL (LSBs)')
    plt.legend()
    plt.grid(True)
    plt.show()

def plot_transfer_curve(expected, combined, ideal):
    """Plot the transfer curve with the ideal line."""
    plt.figure(figsize=(14, 8))
    plt.plot(expected, combined, linestyle='-', label='Combined Measured Output')
    plt.step(expected, ideal, where='post', linestyle='--', label='Ideal Transfer Line')
    plt.title('Transfer Curve of the ADC')
    plt.xlabel('Input Voltage (mV)')
    plt.ylabel('Output Code')
    plt.legend()
    plt.grid(True)
    plt.show()

def plot_code_width_histogram(cw_combined):
    """Plot histogram of code widths."""
    plt.figure(figsize=(14, 6))
    plt.bar(range(len(cw_combined)), cw_combined, color='blue', alpha=0.7, edgecolor='black')
    plt.title('Code Width Histogram')
    plt.xlabel('Output Code')
    plt.ylabel('Code Width (LSBs)')
    plt.grid(True)
    plt.show()
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

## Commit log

2025-01-04 added pcbway logo
2025-01-04 added kicad design files
    [ADC_Testbed.kicad_pcb, ADC_Testbed.kicad_sch]
2025-01-04 added BOM for the PCB
    [BOM.xls]
